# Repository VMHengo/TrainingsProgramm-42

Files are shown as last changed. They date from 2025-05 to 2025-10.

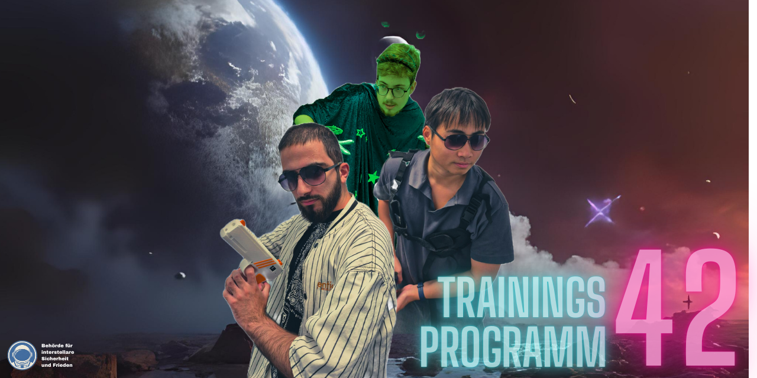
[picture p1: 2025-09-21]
media/presentation/Thumbnail.png

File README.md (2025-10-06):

<h2>"TrainingsProgramm 42" - A Lasertag target shooting game</h2>
<a href="https://youtu.be/itRIaU-dj6U">
  
</a>

## Description
This was a university project about screenless games. We decided to build a fast paced reactive multiplayer game about shooting rapid blinking targets with lasertag pistols.

## Project Realization
Inside the 3D printed gun, we used an Infrared-LED to send signals which are received by each target individually by an IR-receiver. We expanded on this basic idea with focus on user experience by including inside the gun: a speaker for audio feedback, vibration motor for haptic feedback and laser pointer for optic feedback. All components are controlled by a microcontroller, the Arduino Nano.
Inside each target box, which were lasercut and glued together, there is a Arduino Nano controlling a RGB-LED, a battery and an IR-Receiver.
All target boxes are linked by I^2C Communication to the Master, the Pybadge. It controls the game logic and sends and requests data to and from each target box.

## Installation/Construction Overview
Details on installation and construction are in the [manual](Manual.pdf)

To build the game yourself, you need to construct three parts:
### Guns (2x)
- Print the gun from the [3D print file](media/3Dprint/all_parts.gcode.3mf) provided.
- Connect all parts as described in the [manual](Manual.pdf)
- Connect the USB cable to the Nano
- Seal the gun with the three M3 screws

### Receiver Boards (<127x)
- Each Receiver Board can be constructed from glued together lasercut wood boards
  - [Front panel](media/lasercut/frontPanel.pdf)
  - [Side panels](media/lasercut/sidePanels.pdf)
  - [Back panel](media/lasercut/backPanel.pdf)
- These are later connected via I^2C to the central game station

### Central game station
- The case contains the Pybadge. The case is constructed with the following lasercut files:
  - [box](media/lasercut/pybox.pdf)
  - [engraving](media/lasercut/GravurPybox.pdf)
- Additional to the case, we need a seperate box to contain the LED strip which shows the score
  - [score box](media/lasercut/GravurBox.pdf)
- The following files are optional decorations to better game clarity
  - [Gamemode 1 "Standoff" sign](media/lasercut/GravurStandoff.pdf)
  - [Gamemode 2 "Tag A Mole" sign](media/lasercut/GravurTagAMole.pdf)
 
## Outlook and possible improvements
As we kept the project modular and easily expandable in gamemodes there are severals ways to extend the project scope
- We could expand the possible playing field by connecting more receiver boards (currently 5) to the I^2C Bus
- More gamemodes could be added with possible coop, multiple choice quiz etc.
- We could expand the range of the guns to more than 3m with better IR-LEDs and receivers
- We could reduce cost of construction by replacing each Nano in the receiver board with a simpler and cheaper microcontroller
- We could make the parts in the gun less prone to loose connections with cable holders and better designed 3d print models

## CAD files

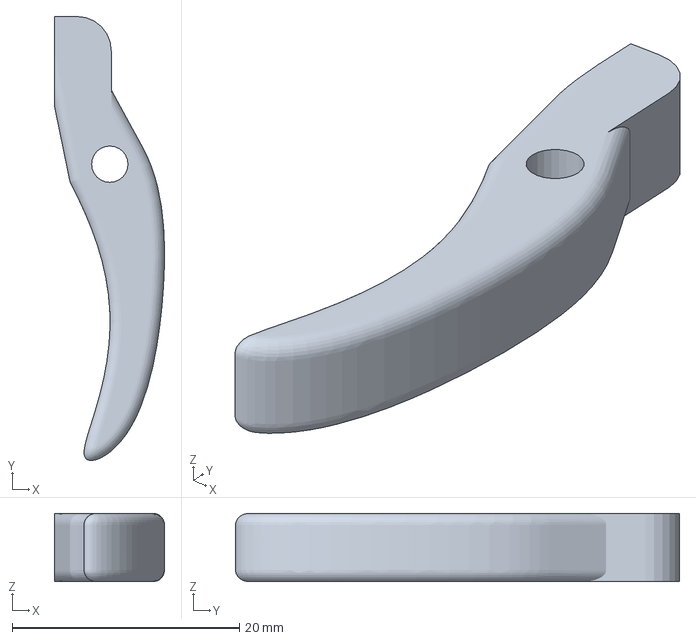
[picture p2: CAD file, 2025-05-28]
media/3Dprint/ir_gun_trigger.3mf
9.68 x 39.1 x 6.00 mm

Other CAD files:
media/3Dprint/ir_gun_shaft.3mf
media/3Dprint/ir_gun_shaft.stl
media/3Dprint/ir_gun_trigger.stl

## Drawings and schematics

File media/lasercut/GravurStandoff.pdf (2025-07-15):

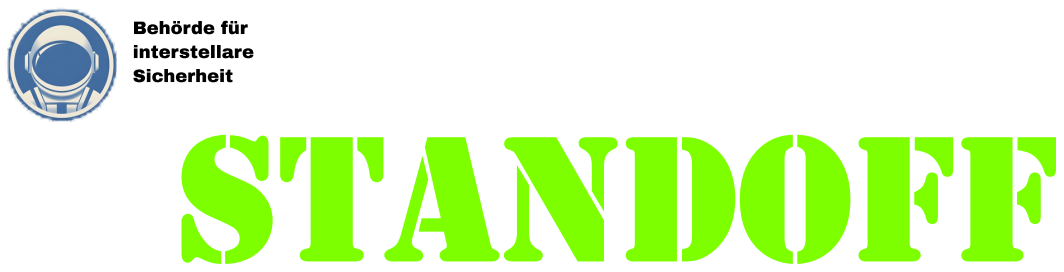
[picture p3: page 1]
STANDOFF

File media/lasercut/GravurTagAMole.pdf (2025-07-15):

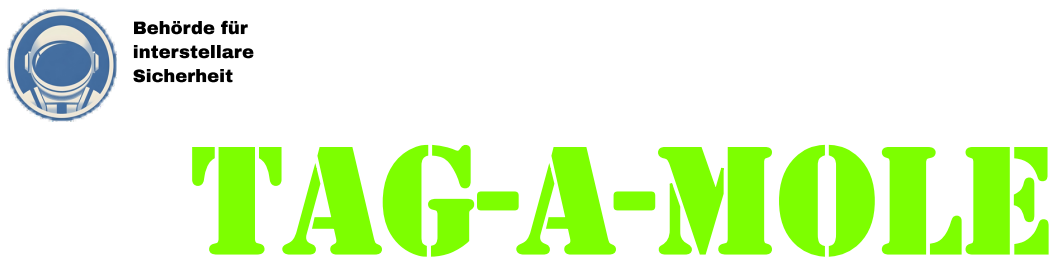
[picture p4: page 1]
TAG-A-MOLE

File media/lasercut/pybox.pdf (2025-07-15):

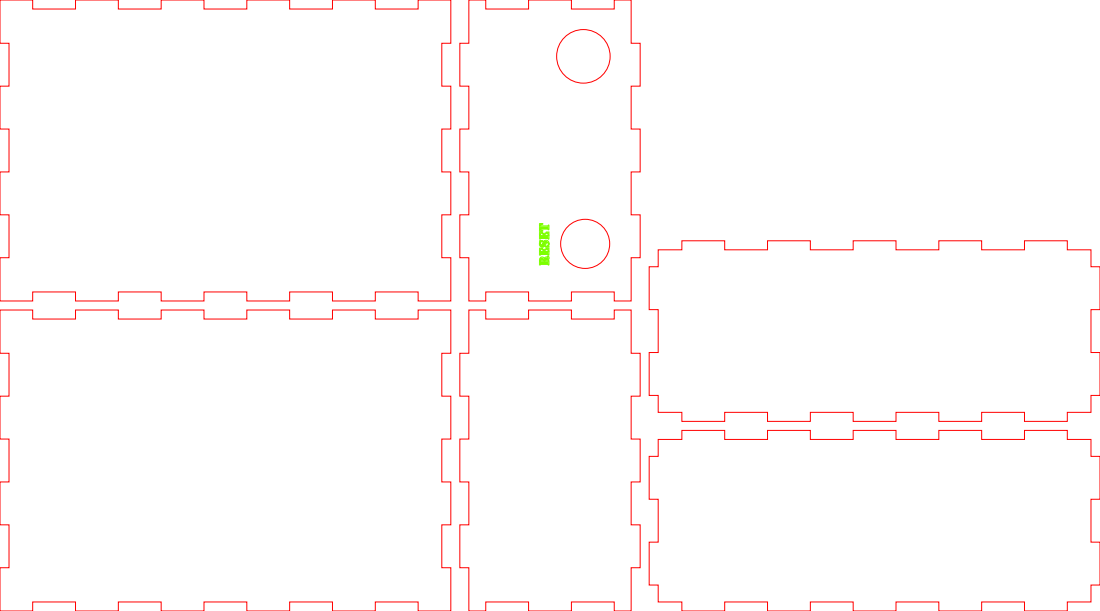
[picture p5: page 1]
RESET

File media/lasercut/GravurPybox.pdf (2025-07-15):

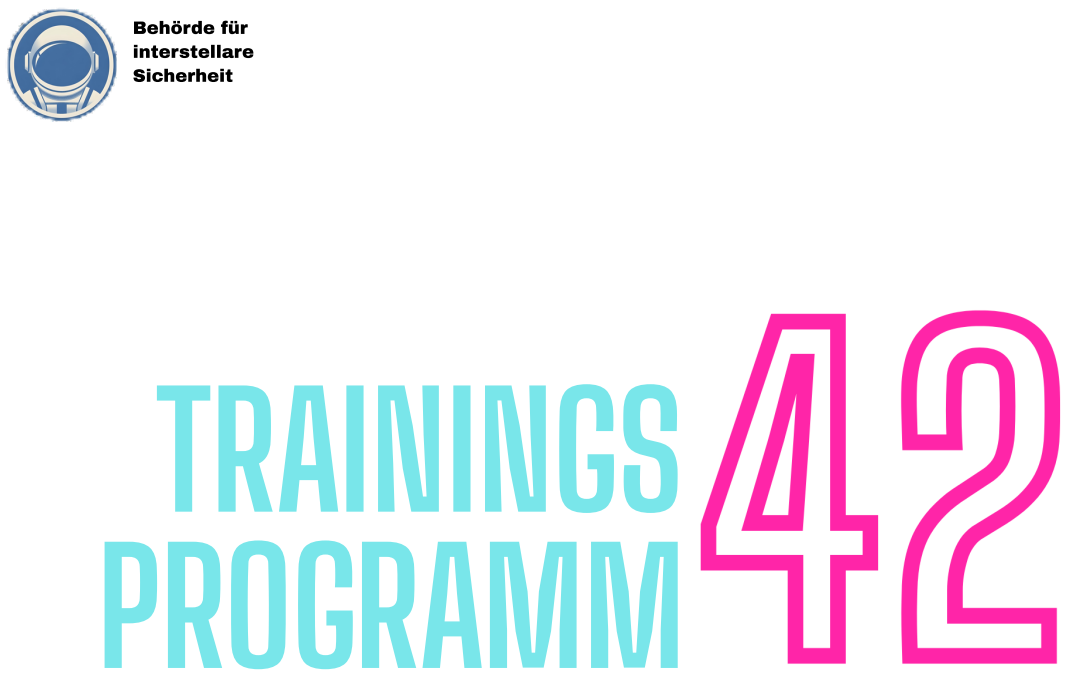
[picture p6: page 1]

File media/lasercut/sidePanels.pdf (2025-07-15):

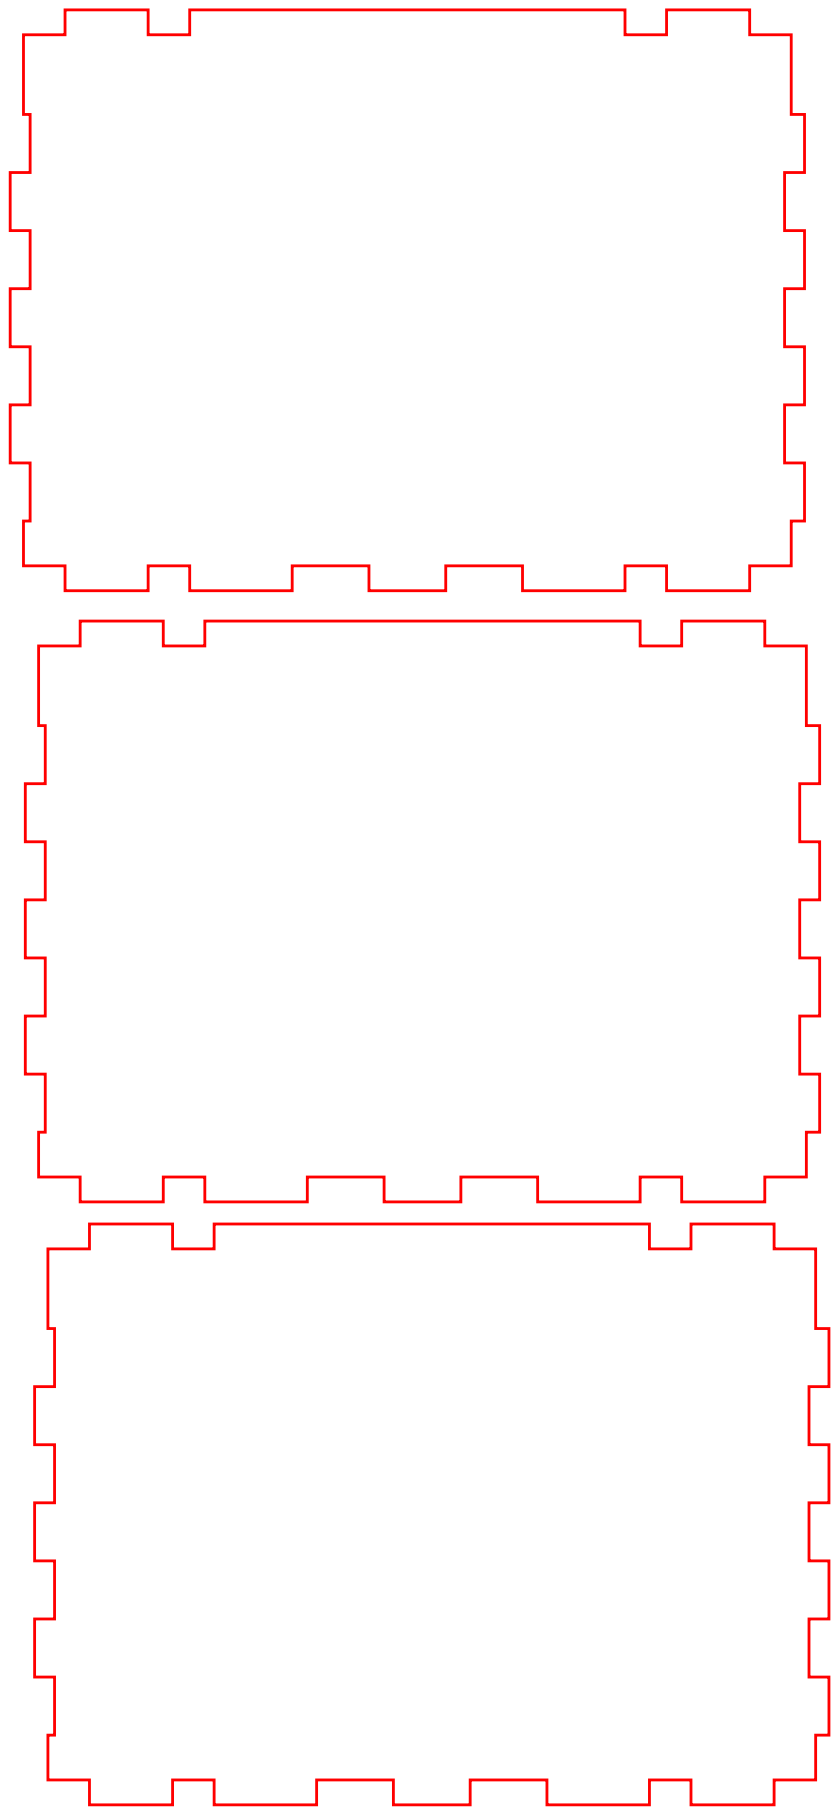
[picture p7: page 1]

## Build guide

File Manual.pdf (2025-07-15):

# Multimodal Madness [M3]

## TRAININGSPROGRAMM 42

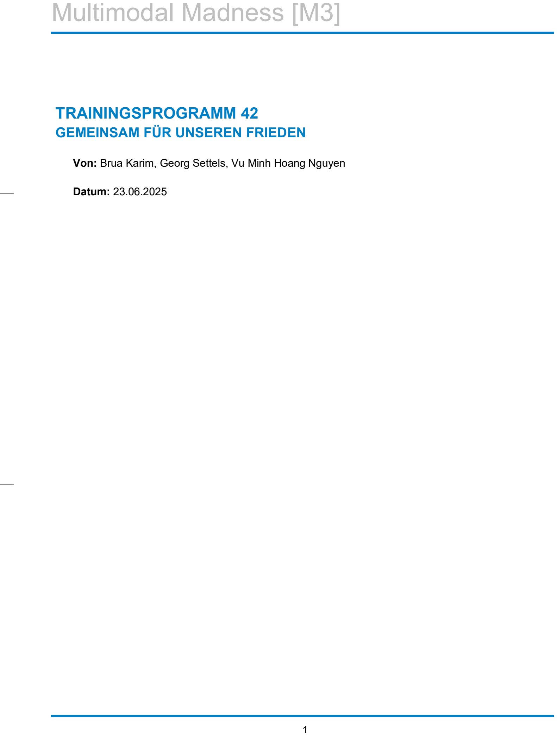
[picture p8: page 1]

GEMEINSAM FÜR UNSEREN FRIEDEN

Von: Brua Karim, Georg Settels, Vu Minh Hoang Nguyen

Datum: 23.06.2025

Manual

## INHALT

## 1. ALLGEMEINES

### 1.1 Projektbezug

Gitlab: https://git.rwth-aachen.de/hoang.nguyen/multimodal-madness-gruppe5

### 1.2 Story

Der neunte Sektor im äußeren Bereich des Imperiums steht unter Beschuss. Eine Gruppe von Systemfeindlichen hat sich zusammengeschlossen, um den Sektor in Anarchie und Chaos zu werfen.

Das Imperium hat daher neue Trainingsprogramme ins Leben gerufen. Auf der Suche nach Ruhm und Ehre hast du dich Trainingsprogramm 42 angeschlossen, um Frieden und Sicherheit in der Galaxis weiterhin zu gewährleisten.
Doch bis dahin ist es noch ein langer Weg, denn du bist nur einer unter Vielen. Zeige mithilfe des neuen Trainingssystem, dass du mehr bist. Steige über Andere und dich selbst hinaus und beweise, dass du der perfekte Kämpfer für unseren Frieden bist.

### 1.3 Aufgabe der Spielerinnen und Spieler

Die Spielerinnen und Spieler sind in einem Trainingsprogramm und müssen gegen Mitspieler und gegen ihre eigenen Grenzen antreten. Durch Minispiele sollen körperliche und geistige Fähigkeiten gestärkt werden, um die Kadetten auf einen kommenden galaktischen Krieg vorzubereiten. Dazu erhalten zwei Spieler IR-Pistolen, mit denen man auf IR-Receiver-Boards schießen kann. Die anzuschießenden Boards werden mit LEDs markiert.

### 1.4 Minispiele

- StandOff(30-60 Sekunden)
Beim StandOff Spiel geht es darum, dass eine Zielfläche grün aufleuchtet und man Diese schneller abschießt als der Gegner. Dies gibt einen Punkt. Der erste Spieler mit 5 Punkten gewinnt das Spiel.
- Tag-A-Mole (45-50 Sekunden)
Das Spiel beginnt mit einem Ziel, welches alle 2 Sekunden wechselt. Alle Sieben Sekunden wird diese Zeit verkürzt und das Ziel wechselt schneller. Der Spieler, der dieses zuerst abschießt, kriegt einen Punkt. Der Spieler mit mehr Punkten gewinnt nach 45 Sekunden das Spiel. Bei Gleichstand wird noch ein entscheidender Punkt gespielt.

## 2. BENÖTIGTE KOMPONENTEN

### 2.1 IR-Pistole (x2)

- IR-LED TSAL6200
- Arduino Nano 3.3V / 5V
- Button
- Piezo-Speaker
- Laser-Modul KY-008
- Vibrationsmotor
- USB-B zu USB 3.0 Kabel
- 3x M3 20mm Schrauben für Plastik
- 2x Transistoren 2N2222A
- Halbes Breadboard GND/VCC Rail
- Jumper Kabel
- F-to-M : 5
- F-to-F : 7
- Widerstände
- 1x 1kΩ
- 1x 100Ω
- 1x 150Ω
- 1x 10kΩ

### 2.2 IR-Receiver Board (Alle Daten pro Zielfläche)

- IR- Receiver TSOP4840
- Arduino MKR WIFI 1010
- 9-Volt Batterie
- 9-Volt Batterie Clip Anschluss
- Schalter
- RGB-LED
- Kleines oder zerschnittenes Breadboard
- 1m langer Schrumpfschlauch
- Jumper Kabel
- M-to-M: 3
- F-to-M : 8
- 3 1m lange M-to-M Kabel
- Widerstände
- 1x 150Ω

### 2.3 pyBadge Zentrale

- pyBadge
- Breadboard
- 1x 3,3V LiPo Akku
- 1x Button
- 1x Neopixel LED-Strip
- Jumper Kabel
- M-to-M: 8

## 3. AUFBAUANLEITUNG

Gun (2x)

Alle Verbindungen (außer zu den Arduino PINs) sollten am besten gelötet werden, da die Verbindungen beim Spielen ungewollt getrennt werden können.

### 1. Drucke die gegeben 3D-Modelle

### 2. Wir arbeiten jetzt im Teil der Gun mit dem rechteckigen Loch im Gehäuse (Linkes Teil)

3. Lege ein 5V Rail und GND Rail in den großen Bereich der Gun.
4. Lege den Arduino Nano in den Handgriff Teil. Die Pins sollten in „Schussrichtung“ zeigen. Der USB-Anschluss soll nach außerhalb der Gun zeigen.

### 5. IR-LED (TSAL6100):

Verbinde den längeren Anschlusspin (-) an GND, den kürzeren über einen 100Ω Widerstand an PIN 2 des Nanos.

### 6. Laser-Modul (KY-008):

Verbinde „S“ über einen 150Ω Widerstand an PIN 3 des Nanos. Der rechte Pin des Lasers muss an GND. Der mittlere Pin bleibt unangeschlossen.

### 7. Button:

Teile ein Kabel in zwei Wege und verbinde ein Ende an den Button. Verbinde einen Weg an PIN 4 des Arduinos, den anderen über einen 10kΩ Widerstand an GND.

Auf derselben Seite des Buttons, verbinde den Pin an das 5V Rail.

### 8. Vibrationsmotor

Verbinde…

- das rote Kabel an das 5V Rail.
- das blaue Kabel an den Collector des Transistors
- parallel dazu eine Diode mit der Anode zum Collector und die Kathode zum 5V Rail
- die Basis des Transistors über einen 1kΩ Widerstand an PIN 5 des Arduinos
- den Emitter des Transistors an GND

### 9. Piezo-Lautsprecher

Verbinde einen PIN des Lautsprechers an PIN 6 des Arduinos, das andere an GND.

Pybadge-Zentrale (x1)

Für Einfachheit und Modularität empfehlen wir hierfür ein Breadboard zu nutzen.

### 10. LED-Strip

Verbinde…

- GND des LED Strips an GND des Arduinos
- 5V des LED Strips an den USB PIN des Arduinos
- Din (mittlerer PIN) des LED Strips an PIN 5 des Pybadges

### 11. Button

Verbinde einen PIN des Buttons an GND, den anderen an PIN 9 des Pybadges.

### 12. Receiver Boards (Aufbau weiter unten)

Erstelle zur Modularität ein „SDA-Rail“ auf dem Breadboard, verbinde den SDA PIN des Pybadges an dieses. Wiederhole dies für SCL.

Jetzt können beliebig viele Receiver Boards an das SDA-, SCL- und GND-Rail verbunden werden.

Receiver Board (beliebig viele)

Wir empfehlen die Nutzung eines GND/5V Rail zur Einfachheit. Wir verwenden für jedes Receiver Board einen neuen Arduino.

### 13. Pybadge Verbindung

Verbinde SDA, SCL und GND des Arduinos an die jeweiligen Rails des Pybadges. Dazu sollten die langen Kabel genutzt werden (optimal >1m)

### 14. IR-Receiver (TSOP4840)

Wir betrachten den Receiver von hinten (flache Seite)

Verbinde…

- den linken PIN (VS) des Receivers an das 5V Rail
- den mittleren PIN (GND) an das GND Rail
- den rechten PIN (OUT) an PIN 2 des Arduinos

### 15. RGB LED

Wir betrachten die LED von der Seite, wo der längste Anschlusspin auf der linken Hälfte ist.

Verbinde…

- den 1. PIN (=Rot) an PIN 3 des Arduinos
- den 2. PIN (=Gemeinsame Anode) über einen 150Ω Widerstand an 5V
- den 3. PIN (=Grün) an PIN 5 des Arduinos
- den 4. PIN (=Blau) an PIN 6

### 16. Powerswitch (Kippschalter + 9V Batterie + Batterieclip)

Verbinde…

- einen der PINs des Schalters an das VIN des Arduinos
- den anderen PIN an die Plusseite eines Batterieclips
- die Minusseite des Batterieclips an GND
- die 9V Batterie an den Batterieclip

Die Verbindungen zur RGB LED und zum Batterieclip sollten angelötet werden, da diese oft zu Wackelkontakten neigen.

## 4. INSTALLATIONSANLEITUNG

### 17. Verbinde alle Teile nach der Aufbauanleitung

### 18. Lade alle hinterlegten Code Dateien herunter

### 19. Schalte den Strom des Receiver Boards aus und verbinde den Arduino über USB an einen

PC. Ändere die Adresse unter „SLAVE_ADDRESS“ zur jeweiligen in der Box beschrifteten Adresse. Wiederhole diesen Schritt für jeden Arduino.

### 20. Verbinde den Pybadge per USB. Drücke zweimal schnell den Reset Knopf. Lade die Datei

„adafruit-circuitpython-pybadge-de_DE-9.2.7.uf2“ in das Laufwerk des pyBadges. Nun sollte man auf dem Laufwerk Circuitpython haben.

21. Legt nun einen Ordner names sfx an und die fünf sfx Dateien in diesen Ordner hochladen.

### 22. Ändere im Code die Variable „SLAVE_COUNT“ zu der jeweiligen Anzahl an Receiver

Boards. Schreibe in die Liste „slave_index“, die Adressen, die auf die Arduinos geschrieben wurden.

### 23. Verbinde die Gun per USB-B zu USB. Ändere im Code die Variable „PLAYER“ zu 1

(Orange Waffe) oder 2 (Blaue Waffe). Schreibe den Code auf die Waffe und wiederhole den Schritt für die andere Gun.

24. Drücke den Reset Knopf für jeden Receiver Arduino. Warte bis alle LEDs weiß sind, dann kann der Pybadge Reset Knopf gedrückt werden. Der Reset ist fertig, wenn alle LEDs lila sind.

Mögliche Fehlerquellen in der Installation:
- Wenn der Arduino in der Arduino DIE nicht erkannt wird, dann gibt es drei häufige Fehlerquellen. 1. Entweder muss der Pybadge noch mit Strom per USB oder Batterie versorgt werden 2. SDA, SCL müssen entfernt und der Arduino resettet werden. 3. Das benutzte USB-Kabel ist kein Datenkabel.
- Wenn einer der LEDs nach Pybadge Reset noch weiß ist, dann kann der Pybadge erneut resettet werden. Danach müsste die übrige LED weiß werden.
- Wenn die LED rot bleibt, dann muss die Batterie ausgetauscht werden

## 5. SPIELANLEITUNG

Nachdem ihr die Anleitungen ausgeführt habt, solltet ihr nun im Menü sein. Dies bedeutet, dass zwei LEDs Lila leuchten sollten. Falls dies nicht der Fall ist oder eine oder mehrere Zielflächen in einem tiefen Rot aufleuchten, solltet ihr nochmals den RESET-Button drücken (Zur Not auch ein paar Mal). Falls sich das Problem dadurch immer noch nicht löst, versucht erst einmal den Strom auszumachen und nochmals anzumachen. Falls das Problem dadurch nicht gelöst wird, müsst ihr direkt den Reset Knopf des Arduinos drücken oder die Batterie austauschen. Sobald die Felder in gelb/orange und zwei Felder Lila leuchten, könnt ihr beginnen.

Das Spiel selbst ist zu 2 Leuten spielbar. Jeder Spieler nimmt sich eine der beiden Waffen und stellt sich ca. 3-4 Meter von der Zielfläche hin. Im Folgenden ist Spieler1, der Spieler mit der orangenen Waffe und Spieler2, der mit der Blauen.

Spieler1 kann nun das zu spielende Minispiel auswählen. Wollt Ihr ein StandOff spielen, muss er mit seiner Waffe auf das rechte Feld schießen, welches Lila leuchtet. Wenn Ihr das Tag-A-Mole Game spielen wollt, schießt auf das linke lila Feld.

Beide Spiele funktionieren im Kern gleich. Nach dem der Start Sound endet, beginnt das Spiel. Es leuchtet immer ein Feld grün auf. Dieses Feld muss getroffen werden. Der Spieler, der zuerst trifft, kriegt einen Punkt. Auch hört ihr einen Sound und seht welcher Spieler dieses Feld getroffen hat.
Unterschiede:

StandOff: Beim StandOff Spiel leuchtet eine LED auf und geht auch erst aus, wenn ein Spieler trifft. Das Spiel endet sobald ein Spieler fünf Punkte hat. Dieser Spieler hat in dem Moment gewonnen. Punkte werden direkt auf dem LED-Strip über der Box angezeigt.

Tag-A-Mole: Beim Tag-A-Mole leuchtet eine Zielfläche nur kurze Zeit auf und wechselt danach. Die Zeitspanne wie lange eine Zielfläche leuchtet, wird dabei kürzer. Wer ein Feld trifft, kriegt einen Punkt. Das Spiel endet immer nach 45 Sekunden. Der Spieler mit mehr Punkten gewinnt nach dieser Zeit. Punkte werden hierbei als Prozente auf dem LED-Strip angezeigt.

Jeder Spieler hat zudem fünf Schüsse bevor das Magazin nachgeladen werden muss. Dies passiert automatisch und ihr könnt einen kurzen Moment nicht schießen. Also nicht durchfeuern!

Viel Spaß beim Spielen

## 6. BEKANNTE PROBLEME & FIXES

### 6.1 Das Interferenzproblem

Wir benutzen IR-LEDs, welche eine Bitsequenz über das Protokoll NEC entsenden, welche daraufhin von einem IR-Receiver gelesen wird. Wir wollten die Spieler damit unterscheiden, dass beide jeweils unterschiedliche Sequenzen schicken. Dabei ist uns aber erst sehr spät aufgefallen, dass Interferenzen entstehen, wenn beide Spieler zur gleichen Zeit schießen, da NEC ungefähr 100ms das Signal entsendet und sich beide Wellen somit gegenseitig beeinflussen und die Bitsequenz abändern.
Der Fix war am Ende, dass wir eine Waffe nur sehr kurz schießen lassen, sodass diese definitiv richtig sendet, wenn sie zuerst schießt und die zweite Waffe weiterhin normal schießen lassen, sodass bei einer Abänderung der Bitsequenz klar ist, dass diese Waffe zuerst geschossen wurde.

### 6.2 Das Reset Problem

Bei einem Fehler sowie beim Start des Spiels musste man alle Arduino MKR sowie den pyBadge einmal resetten. Auch konnte man das Spiel nicht mittendrin abbrechen und ins Menü zurückkehren. Die Lösung war ein Interrupt, welcher auf Knopfdruck aktiviert wurde und zentral vom pyBadge aus die Arduinos resettet hat. Dieser hatte aber als Problem, dass manchmal die Arduinos nicht resettet wurden, sondern vom Datenbus gekappt wurden und man alles nochmal resetten musste.
Jeder unserer versuchten Fixe hat das Problem nicht komplett gelöst bekommen. Die beste Möglichkeit war einfach alle einzelnd zu resetten. Sobald das Spiel nämlich einmal funktioniert, tritt der Fehler auch nicht mehr oder nur sehr selten auf.

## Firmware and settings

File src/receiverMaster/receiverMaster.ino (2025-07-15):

// VERSION: 5.7.2025 3:36
#include <Wire.h>
#include <Adafruit_Arcada.h>
#include <Adafruit_NeoPixel.h>
#include "sam.h"
#include <math.h>

#define LED_PIN    5. // Pin an der unser LED-Strip angeschlossen ist
#define LED_COUNT 10 // Anzahl der LEDs an unserem Strip

#define SLAVES_ANZAHL 5 // Anzahl wie viele Slaves wir haben
#define GAMEMODE_ANZAHL 2 // Anzahl wie viele GameModes es gibt
uint8_t slaves[SLAVES_ANZAHL] = {0x10, 0x20, 0x30, 0x40, 0x50}; // Addressen der Slaves
uint8_t gameModes[GAMEMODE_ANZAHL] = {0x10, 0x20}; // Addressen der Slaves die einen GameMode haben
Adafruit_NeoPixel strip(LED_COUNT, LED_PIN, NEO_GRB + NEO_KHZ800);

#define SFX_COUNT 6 // Wie viele SFX-Files wir haben
Adafruit_Arcada arcada;
File sfxFile;
volatile bool playing = false; // Ob ein SFX file gerade abspielt

#define RST_BTN_PIN // Pin auf dem unserer Reset-Button ist


bool inMenu = true; // Zustand ob wir im Menü sind
uint8_t gameMode = 0; // Zustand in welchem Game wir uns befinden


// Inititalisiere alle Objekte für unseren LED-Strip und setzte die Pins in den richtigen Modus
void setup() {
  Serial.begin(9600);

  if (!arcada.arcadaBegin())
  {
    errorReporter("Fatal error: Arcada library failed.");
  }
  if (!arcada.filesysBegin()) { 
    errorReporter("Fatal error: Filesystem failed.");
  }

  Wire.begin();
  strip.begin();
  strip.show(); // Initialize all pixels to 'off'
  pinMode(RST_BTN_PIN, INPUT_PULLUP);
  attachInterrupt(digitalPinToInterrupt(RST_BTN_PIN), resetAll, FALLING); // Der Button soll ein Interrupt auslösen
  delay(2000);
}


void loop() {
  if(inMenu){
    handleMenu();
  }else if(gameMode == 0x10){
    gameMode1();
    gameMode = 0;
  }else if(gameMode == 0x20){
    gameMode2();
    gameMode = 0;
  }else{
    //Serial.println("BIG ERROR");
  }
}

// Logik für unser Menü
void handleMenu(){
  gameMode = 0;
  for(int i=0; i < GAMEMODE_ANZAHL; i++){ // Sende an die Slaves mit einem GameMode den Befehl ins Menü zu gehen
    Wire.beginTransmission(gameModes[i]);
    Wire.write(1);
    Wire.endTransmission();
  }
  resetScoreboard();
  loadSFX(4);
  gameMode = requestGameModeFromSlaves(); // Erhalte den GameMode der ausgewählt wurde
  Serial.println(gameMode);
  Wire.beginTransmission(gameMode);
  Wire.write(3);  // Code 3 = Spiele Animation von Auswahl ab
  Wire.endTransmission();
  loadSFX(3);
  delay(1800); // Zeit der LED Animation
  broadcastCmd(2); // Setzte alle Slaves in einen sicheren zustand
  inMenu = false;
}

// Logik des ersten Spiels, es gewinnt derjenige, der zuerst 5 Punkte erreicht
void gameMode1(){
  randomSeed(millis());
  loadSFX(5);
  long slave_index;
  uint32_t currentWinner;
  int orangePoints = 0;
  int bluePoints = 0;
  int requiredPoints = 5; // HIER MIN. PUNKTZAHL ZUM GEWINNEN ÄNDERN
  while(orangePoints != requiredPoints && bluePoints != requiredPoints){
    slave_index = random(0, SLAVES_ANZAHL); // Slave der zur Zielfläche werden soll
    currentWinner = activateOneTargetGM1(slaves[slave_index]); // Ermittle denjenigen der Zuerst draufgeschossen hat
    if(currentWinner == 0x00000001){
      strip.setPixelColor(orangePoints, 255, 255, 0);
      strip.show();
      orangePoints += 1;
    }else if(currentWinner == 0x00000002){
      strip.setPixelColor(9-bluePoints, 0, 0, 255);
      strip.show();
      bluePoints += 1;
    } 
  }
  if(orangePoints == requiredPoints){
    broadcastCmd(98); // Gewinn Animation für Orange
    setScoreboard(255,255,0);
  }else if(bluePoints == requiredPoints){
    setScoreboard(0,0,255); 
    broadcastCmd(99); // Gewinn Animation für Blau
  }
  loadSFX(0);
  delay(5000); // 5 Sekunden sieger Animation puffer um zu Gewährleisten, dass auf slaves Seite nichts kaputt geht
  inMenu = true;
}

// Logik des zweiten Spiels, es gewinnt derjenige, der nach 45sek mehr Punkte hat
void gameMode2(){
  randomSeed(millis());
  loadSFX(5);
  long slave_index = 0;
  uint32_t currentWinner;
  int orangePoints = 0;
  int bluePoints = 0;
  unsigned long startTime = millis(); 
  unsigned long newTimeWD = millis(); // Variable die benötigt wird, um alle 10 Sekunden timeForShot runterzusetzen
  unsigned long timeForShot = 2000; // Die Zeit die man hat um eine Zielfläche anzuschießen
  uint8_t lastSlave = 0x00; // Variable um abzuspeichern wlcher Slave zuletzt eine Zielfläche war
  while((startTime + 45000) >= (millis()) || orangePoints == bluePoints){ // Schleife geht solange bis es einen Gewinner gibt UND mind. 45sek um sind
    if(newTimeWD + 10000 <= millis()){ // Logik um alle 10 sekunden timeForShot runterzusetzen
      if((startTime + 45000) >= (millis())){
        timeForShot -= 250;
        newTimeWD = millis();
      }
    }
    do{
      slave_index = random(0, SLAVES_ANZAHL); 
    }while((uint8_t) slave_index == lastSlave); // Wähle solange einen neues Ziel (Slave) aus, bis er nicht mehr der gleiche ist wie unser letztes Ziel
    lastSlave = (uint8_t) slave_index;

    currentWinner = activateOneTargetGM2(slaves[slave_index], timeForShot); // Erhalte denjenigen der auf die Zielfläche zuerst geschossen hat (wenn überhaupt)
    if(currentWinner == 0x00000001){
      orangePoints += 1;
    }else if(currentWinner == 0x00000002){
      bluePoints += 1;
    }
    scoreBoardGM2(orangePoints, bluePoints); // Update das Scoreboard
  }
  if(orangePoints>bluePoints){
    setScoreboard(255,255,0);
    broadcastCmd(98); // Gewinn Animation für Orange
  }else if(bluePoints > orangePoints){
    setScoreboard(0,0,255);
    broadcastCmd(99); // Gewinn Animation für Blau
  }
  loadSFX(0);
  delay(5000); // 5 Sekunden sieger Animation puffer um zu Gewährleisten, dass auf slaves Seite nichts kaputt geht
  inMenu = true;
}

// Sendet den command (cmd) an jeden einzelnen Slave in unserem "slaves" array
void broadcastCmd(int cmd){
  for(int i=0; i < SLAVES_ANZAHL; i++){
    Wire.beginTransmission(slaves[i]);
    Wire.write(cmd);
    Wire.endTransmission();
  }
}

// Frage die Slaves nacheinander ab auf wen geschossen wurde, derjenige der getroffen wurde gibt seine Adresse. Diese Addresse fungiert als gameMode, es werden nur gameModes akzeptiert die im entsprchenden gameModes Array sind
// ACHTUNG SLAVES DÜRFEN NUR ADRESSEN DER FORM 0xZZ haben, sonst funktioniert das mit dem Casten nicht in von uint32_t zu uint8_t weil bits weggeschnitten werden
uint8_t requestGameModeFromSlaves(){
  int i = 0;
  uint32_t response = 0;
  while (!valueInGameModes((uint8_t) response)) {
    Wire.requestFrom(gameModes[i], sizeof(response));
    if (Wire.available() == 4) {
      for (int j = 0; j < sizeof(response); j++) {
        ((uint8_t *)&response)[j] = Wire.read();
      }
    }
    delay(100);
    i = (i + 1) % GAMEMODE_ANZAHL;
  }
  return (uint8_t) response;
}

// Checkt, ob "value" im gameModes Array ist
bool valueInGameModes(uint8_t value) {
  for (int i = 0; i < GAMEMODE_ANZAHL; i++) {
    if (gameModes[i] == value) {
      return true;
    }
  }
  return false;
}

// Ein einzelner Slave leuchtet grün auf, wir warten bis dieser angeschossen wurde, dann erhalten wir als rückgabewert, wer auf diesen geschossen hat
uint32_t activateOneTargetGM1(uint8_t slave){
  delay(1700 + random(0, 2000)); // Nach 1.7-3.7 Sekunden soll das Target aktiv werden
  Wire.beginTransmission(slave);
  Wire.write(10);  // Code 10 = Start von GameMode1
  Wire.endTransmission();

  uint32_t response = 0;
  while(response != 0x00000001 && response != 0x00000002 && response!= 0x00000003){ 
    Wire.requestFrom(slave, sizeof(response));
    if(Wire.available() == 4){
      for(int i=0; i<sizeof(response); i++){
        ((uint8_t *)&response)[i] = Wire.read();
      }
    }
    delay(200);
    Serial.println(response);
  }
  Wire.beginTransmission(slave);
  Wire.write(3);  // Code 3 = Animation
  Wire.endTransmission();
  loadSFX(1);
  delay(1800); // LED ANIMATION TIME, garantiert, dass die sachen nicht out of sync sind (i.e. nächster cmd wird gesendet bevor led animation fertig)
  return response;
}

// Ein einzelner Slave leuchtet grün auf, dieser muss in "givenTime" angeschossen werden, dann erhalten wir als rückgabewert wer auf diesen geschossen hat, sonst geht der Slave wieder aus und es gibt keinen Gewinner
uint32_t activateOneTargetGM2(uint8_t slave, unsigned long givenTime){
  Wire.beginTransmission(slave);
  Wire.write(22);  // Code 2 = Start von GameMode2 
  Wire.endTransmission();

  unsigned long startTime = millis();
  uint32_t response = 0;

  while(response != 0x00000001 && response != 0x00000002 && response!= 0x00000003 && (startTime + givenTime) >= (millis())){ 
    Wire.requestFrom(slave, sizeof(response));
    if(Wire.available() == 4){
      for(int i=0; i<sizeof(response); i++){
        ((uint8_t *)&response)[i] = Wire.read();
      }
    }
    delay(200);
  }

  if(response == 0x00000001 || response == 0x00000002 || response == 0x00000003){ // Nur wenn einer drauf geschossen hat wird dies Ausgeführt
    Wire.beginTransmission(slave);
    Wire.write(3);  // Code 3 = Animation
    Wire.endTransmission();
    loadSFX(1);
    delay(50); // LED ANIMATION TIME, garantiert, dass die sachen nicht out of sync sind (i.e. nächster cmd wird gesendet bevor led animation fertig)
  }

  Wire.beginTransmission(slave);
  Wire.write(23); // Resette den slave in einen Safe-State (aber noch im Zustand von GameMode2)
  Wire.endTransmission();
  return response;
}

// Setzte den Ganzen Strip aif die Farbe (r,g,b)
void setScoreboard(int r, int g, int b){
  for(int i=0; i<LED_COUNT; i++){
      strip.setPixelColor(i, r, g, b);
  }
  strip.show();
}

// Mache den ganzen Strip aus
void resetScoreboard(){
  setScoreboard(0,0,0);
}

// Spiele die SFX-File ab mit dem index
void loadSFX(int index) {
  index = (SFX_COUNT -1) - index; // index shift
  sfxFile = arcada.openFileByIndex("/sfx", index, O_READ, "wav");
  if (!sfxFile) {
    errorReporter("Fatal error: No sound file present.");
  }

  Serial.println("Loading sound file...");
  
  uint32_t sampleRate;

  // load wav information, enable speakers and set interrupt for sampling
  wavStatus status = arcada.WavLoad(sfxFile, &sampleRate);
  if ((status == WAV_LOAD) || (status == WAV_EOF)) {
    arcada.enableSpeaker(true);
    // create own interrupt
    arcada.timerCallback(sampleRate, wavOutCallback);
  } else {
    errorReporter("Fatal error: Sound file corrupted.");
  }

   do { // Repeat this loop until WAV_EOF or WAV_ERR_*
    if (arcada.WavReadyForData()) {
      yield();
      status = arcada.WavReadFile();
    }
    yield();
  } while ((status == WAV_OK) || (status == WAV_LOAD));

  // Audio might be continuing to play at this point!
  while (playing)   yield();
  // now we're really done
  sfxFile.close();
  Serial.println("Ende Sfx");
}

// Hilfsfunktion für die loadSFX funktion
void wavOutCallback(void) {
  wavStatus status = arcada.WavPlayNextSample();
  if (status == WAV_EOF) {
    // End of WAV file reached, stop timer, stop audio
    arcada.timerStop();
    arcada.enableSpeaker(false);
    playing = false;
  } else {
    playing = true;
  }
}

// Error Reporter bei fehlern
void errorReporter(const char *error) {
  Serial.begin(9600);
  Serial.println(error);

  // busy wait to keep USB connections, etc. running
  while (true) {
    yield();
  }
}

// Funktion die aufgerufen wird, wenn der Reset-Button gedrückt wird. Alle Slaves und der Pybadge werden resettet
void resetAll(){
  setScoreboard(255,0,0);
  resetSlaves();
  NVIC_SystemReset();
}

// Generische funktion
void test(){
  Serial.println("Button wurde gedrückt!");
}

// Logik um unseren Scoreboard in GameMode2 zu setzen. Die Punkte werden Prozentual zur Gesammtpunktzahl angezeigt
void scoreBoardGM2(int pointsOrange, int pointsBlue){
  int totalPoints = pointsOrange + pointsBlue;
  if(pointsOrange > 0 && pointsBlue == 0){
    setScoreboard(255,255,0);
  }else if(pointsBlue > 0 && pointsOrange == 0){
    setScoreboard(0,0,255);
  }else if(pointsOrange > pointsBlue){
    int percentageBlue = round(10 * ((float)pointsBlue / totalPoints));
    int percentageOrange = round(10 * ((float)pointsOrange / totalPoints));
    for(int i=0; i < percentageBlue; i++){
      strip.setPixelColor(9-i, 0, 0, 255);
    }
    for(int i=0; i < percentageOrange; i++){
      strip.setPixelColor(i, 255, 255, 0);
    }
  }else if(pointsOrange != 0 && pointsBlue != 0){
    int percentageBlue = round(10 * ((float)pointsBlue / totalPoints));
    int percentageOrange = round(10 * ((float)pointsOrange / totalPoints));
    for(int i=0; i < percentageOrange; i++){
      strip.setPixelColor(i, 255, 255, 0);
    }
    for(int i=0; i < percentageBlue; i++){
      strip.setPixelColor(9-i, 0, 0, 255);
    }
  }
  strip.show();
}

// Resette alle Slaves
void resetSlaves(){
  for(int i=0; i < SLAVES_ANZAHL; i++){
    Wire.beginTransmission(slaves[i]);
    Wire.write(100); // Code 100 = Slave soll sich resetten
    Wire.endTransmission();
    delay(250);
  }
}

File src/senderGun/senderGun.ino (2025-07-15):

#include <IRremote.h>

#define PLAYER 1 // Hier setzten für welchen Player der Code gilt (1 Orange, 2 Blau)

const int irLedPin = 2;
const int speakerPin = 6;  // Pin der PWM kann
const int buttonPin = 4;
const int laserPin = 3;
const int motorPin = 5; // Gemeint ist der VibrationsMotor

const int vibrationStrength = 150;
const int feedbackDuration = 150; //in ms

uint32_t message = 0x00000001; // Feste Bit Sequenz die Spieler 1 abfeuert

bool triggerReleased = true; // Wurde der Trigger losgelassen

int currentBullet = 0; // An welchem Schuss  befinden wir uns gerade

const int chords[5][5] = { // Für die einzelnen Schüsse
  {440, 622, 0, 0, 0},       // Schuss 1: A + D# 
  {392, 523, 622, 0, 0},     // Schuss 2: G + C + D# 
  {349, 494, 587, 659, 0},   // Schuss 3: F + B + D + E 
  {330, 440, 554, 622, 698}, // Schuss 4: E + A + C# + D# + F
  {311, 392, 466, 523, 622}  // Schuss 5: D# + G + A# + C + D# 
};

const int chordLengths[5] = {2, 3, 4, 5, 5}; // Anzahl Töne pro Akkord
const int chordTotalDuration = 200;  // Dauer jedes Akkords
const int pauseBetweenShots = 150;

uint16_t sigA[] = {900, 450, 560, 560};  // längeres zweites ON

IRsend irsend;


void setup() {
  pinMode(buttonPin, INPUT);
  pinMode(laserPin, OUTPUT);
  pinMode(motorPin, OUTPUT);
  IrSender.begin(irLedPin);  // Start von IR-Transmitter an pin 8
}

// Spielt den Akkord der freqs übergeben wurde, count stellt sicher, dass im Endeffekt alle verschiedneen AKkorde geleiche länge haben (aber ein Ton ggf unterschiedlich lang ist)
void playChord(const int* freqs, int count) {
  int singleDuration = chordTotalDuration / count;
  for (int i = 0; i < count; i++) {
    if (freqs[i] > 0) {
      tone(speakerPin, freqs[i]);
      delay(singleDuration);
      noTone(speakerPin);
    }
  }
}

// Fester Chord, der Signalisiert das die Gun Ready ist nach dem Reloaden
void playReadyChord() {
  int readyChord[] = {261, 329, 392};
  for (int i = 0; i < 3; i++) {
    tone(speakerPin, readyChord[i]);
    delay(70);
    noTone(speakerPin);
  }
}

// SPielt unseren Reloadsound ab
void playReloadSound() {
  for (int f = 300; f <= 1500; f += 25) {
    tone(speakerPin, f);
    delay(15);
  }
  noTone(speakerPin);
  playReadyChord();
}

// Macht den Laser und den Motor für "ms" millisekunden an
void feedbackShot(int ms){
  digitalWrite(laserPin, HIGH);
  analogWrite(motorPin, vibrationStrength);
  delay(ms);
  analogWrite(motorPin, 0);
  delay(100);
  digitalWrite(laserPin, LOW);
}

void loop() {
  if ((digitalRead(buttonPin) == HIGH) && triggerReleased) { //Falls wir ein Signal vom Button erhalten und der trigger losgelassen wurde
    triggerReleased = false;
    if(PLAYER == 1){
      IrSender.sendNEC(message, 32);
    }else if(PLAYER == 2){
      IrSender.sendRaw(sigA, sizeof(sigA), 38);
    }
    
    feedbackShot(feedbackDuration);
    
    playChord(chords[currentBullet], chordLengths[currentBullet]);

    currentBullet = (currentBullet + 1) % 5;
  }else if ((digitalRead(buttonPin) == LOW) && !triggerReleased){ // Falls der Button losgelassen wurde und der Trigger gedrückt wurde
    triggerReleased = true;
    if(currentBullet == 0){ // Reloading Wird ausgeführt, wenn wir durch das ganze Magazin (5 Schuss) gegangen sind
      delay(100);
      playReloadSound();
    }
  }
}

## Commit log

2025-05-23 added prototype 3d model
    [LED_lens_test.stl, LT_Ammo_count.stl, LT_Mag_weighted.stl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]
2025-05-23 added best option for 3d model
    [ir-gun_left.stl, ir-gun_right.stl, ir-gun_whole.stl]
2025-05-28 small addition of laser module
    [ir-gun-modified.stl, ir-gun-original.stl, ir-gun.3mf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]
2025-06-17 Fortschrittsbericht und PPP
2025-06-17 Fortschrittsbericht und PPP (überarbeitet)
2025-06-17 ZIP file mit der Abgabe
2025-06-23 pull commit
    [LED_lens_test.stl, LT_Ammo_count.stl, LT_Mag_weighted.stl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]
2025-07-15 Receiver Board Support
2025-07-15 Receiver Board Front
2025-07-15 Receiver Board Back
2025-07-15 LED Strip Box
2025-07-15 Gravur StandOff Spiel
2025-07-15 Jeden Code mit Kommentaren geadded, das Video und die sfx files
2025-07-15 Rohr als stl Datei
    [ir_gun_shaft.stl]
2025-07-15 Rohr als 3mf Datei
    [ir-gun-shaft.3mf]
2025-07-15 Waffentrigger als stl Datei
    [ir_gun_trigger.stl]
2025-07-15 Waffentrigger als 3mf Datei
    [ir_gun_trigger.3mf]
2025-07-15 Deleted Old Folders
    [ir-gun-shaft.3mf, ir-gun.3mf, ir_gun_trigger.3mf]
2025-09-21 cleaned up repo
    [ir-gun-shaft.3mf, ir_gun_shaft.3mf, ir_gun_shaft.stl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]
